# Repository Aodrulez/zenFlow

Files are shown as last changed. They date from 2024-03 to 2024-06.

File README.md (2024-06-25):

# ZenFlow
## My endgame 18 key custom keyboard 

Kailh Choc V1 variant:
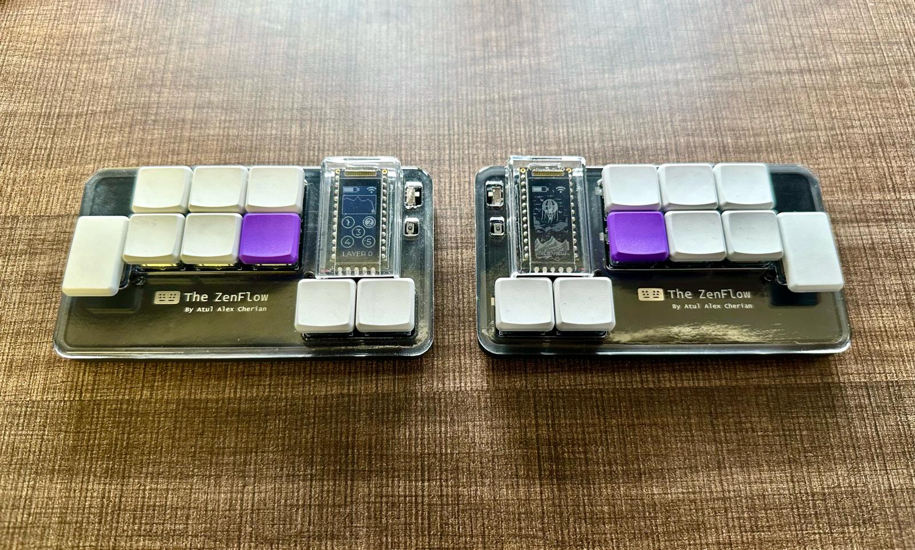
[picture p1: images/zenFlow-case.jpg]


MX 3d printed + hand wired variant:
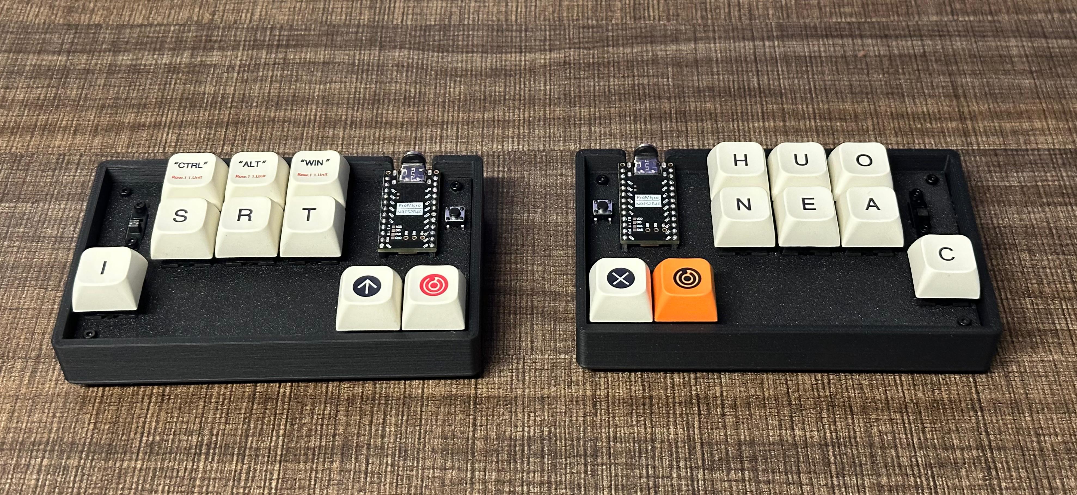
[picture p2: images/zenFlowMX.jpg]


ZenFlow is a fully custom split wireless keyboard made using Ergogen + KiCad. It's powered by [ZMK](https://zmk.dev/). Check [keymap](./keymap) for more details. 
## Features

- 18 keys
- Split, ortholinear
- Fully wireless, compatible with ZMK
- Supports both hot-swap as well as direct soldering of Kailh Choc v1 switches
- Supports nice!view displays
- Reversible PCB
- Mounting holes for a case

Note (Kailh Choc V1 variant): `Solder all the reversible pads & components (except battery, power switch & reset button) on the bottom side of each half as instructed on the PCB` 

## Requirements (Kailh Choc V1 variant)
| Part | Specification |
| --- | --- |
| MCU | 2x nice!nano or SuperMini |
| Battery | 2x Lipo battery (301230)|
| Power switch | 2x MSK-12C02 or compatible |
| Reset button | 2x B3U-1000P(M) |
| Switches | 18x Kailh Choc v1 |
| Keycaps | 16x Kailh Choc v1 1u & 2x Kailh Choc v1 2u |
| Hotswap sockets (Optional) | 18x Kailh Choc v1 |
| Display (Optional) | 2x nice!view |

## Credits
- Ben Vallack for the videos & his Piano keyboard for inspiration
- [Ergogen](https://docs.ergogen.xyz/) which was used for most of the designing & FlatFootFox for the tutorial series 
- [ZMK](https://zmk.dev/) community in general

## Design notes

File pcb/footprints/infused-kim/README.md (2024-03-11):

# @infused-kim's ergogen PCB footprints

> **Warning**
>
> These footprints have not been tested and are still under active development. Use them at your own risk.

1. [Installation](#installation)
    1. [How to add the footprints as a git submodule](#how-to-add-the-footprints-as-a-git-submodule)
    2. [How to use them in your ergogen config](#how-to-use-them-in-your-ergogen-config)
    3. [How to update the submodule](#how-to-update-the-submodule)
    4. [How to clone your ergogen repo](#how-to-clone-your-ergogen-repo)
2. [How to design or modify ergogen footprints](#how-to-design-or-modify-ergogen-footprints)
3. [License](#license)

## Installation

### How to add the footprints as a git submodule

Add the footprint library as a git submodule to your project...

```bash
git submodule add git@github.com:infused-kim/kb_ergogen_fp.git ergogen/footprints/infused-kim/
```

Make sure to adjust the path to a subfolder in your ergogen folder (`ergogen/footprints/infused-kim/` in the example above.)

### How to use them in your ergogen config

You can then use the footprints in your ergogen config.yaml:

```yaml
[...]
pcbs:
    your_keyboard:
        footprints:
            # Controller
            promicro:
                what: infused-kim/nice_nano_pretty
                params:
                    traces: true
                    show_via_labels: false
[...]
```

### How to update the submodule

To update to a newer version...

```bash
# Pull updates inside the submodule repo
cd ergogen/footprints/infused-kim/
git checkout main
git pull

# Update the submodule in the parent repo
cd ..
git add .
git commit -m "Updated infused-kim footprint submodule"
```

### How to clone your ergogen repo

Users who clone your ergogen repo, must also update the submodule. So you should instruct them to either clone with the `--recursive` mode...

```bash
git clone --recursive git@github.com:your-user/your-keyboard.git
```

Or do init and update the submodules in a repo that was already cloned repo without the `--recursive` argument...

```bash
git clone git@github.com:your-user/your-keyboard.git
cd your-keyboard
git submodule init && git submodule update
```

Git will load exactly the same version of the footprints that you used. So you don't need to worry about accidental updates to incompatible future versions.

## How to design or modify ergogen footprints

I wrote a [guide on how to convert KiCad footprints to ergogen that you can find here](https://www.notion.so/nilnil/Convert-Kicad-Footprint-to-Ergogen-8340ce87ad554c69af4e3f92bc9a0898?pvs=4).

If you want to modify any of the footprints here, you can find many of the original KiCad v5 footprint files I used or created in the [./kicad_footprints/](./kicad_footprints/) directory.

## License

**TLDR:**

- Personal use with attribution
- Commercial use not allowed

This work is licensed under a
[Creative Commons Attribution-ShareAlike 4.0 International License][cc-by-sa].

[][cc-by-sa]

[cc-by-sa]: http://creativecommons.org/licenses/by-sa/4.0/
[cc-by-sa-image]: https://licensebuttons.net/l/by-sa/4.0/88x31.png
[cc-by-sa-shield]: https://img.shields.io/badge/License-CC%20BY--SA%204.0-lightgrey.svg

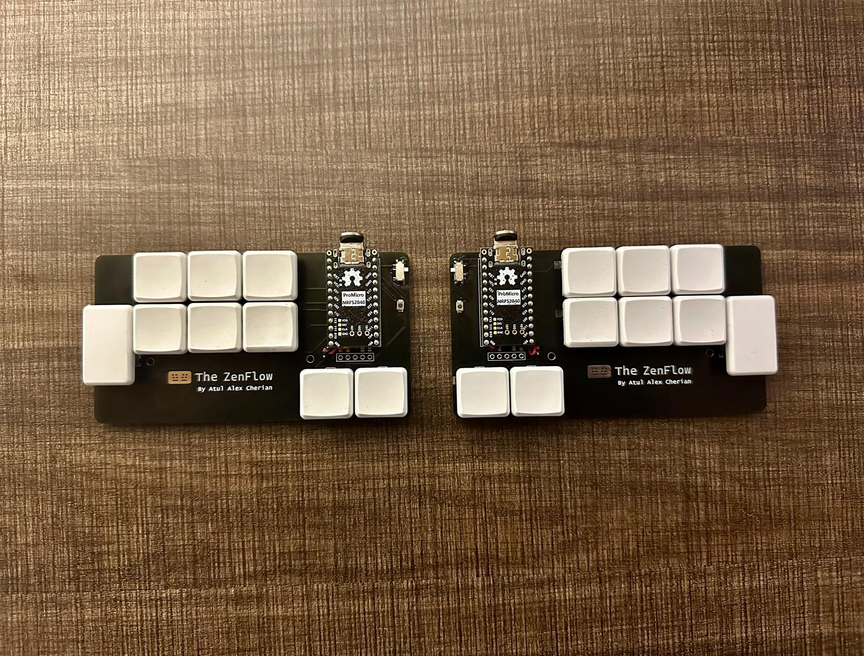
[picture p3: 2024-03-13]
images/zenFlow.jpg

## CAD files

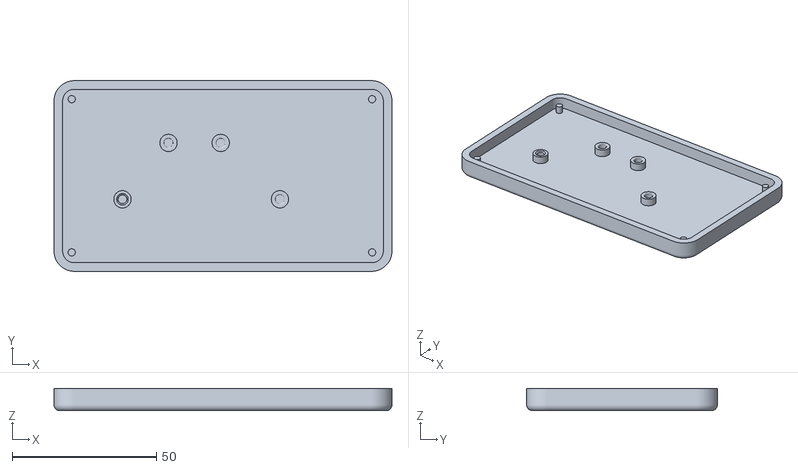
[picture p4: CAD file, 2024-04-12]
case/LowProfile/zenFlow-base-left.stl
117.0 x 66.0 x 7.70

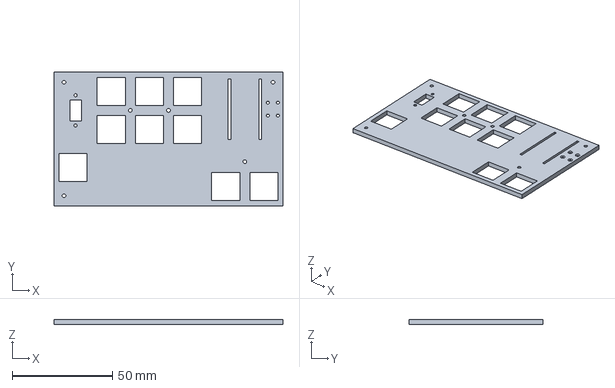
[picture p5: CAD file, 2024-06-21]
case/MX/zenFlowV2SwitchPlate.3mf
114.3 x 66.7 x 2.50 mm

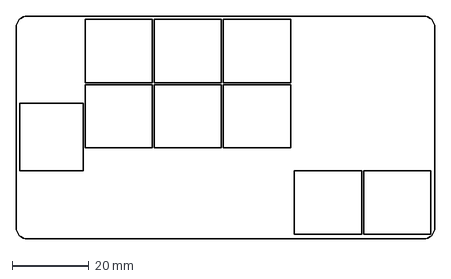
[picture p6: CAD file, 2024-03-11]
pcb/output/outlines/combo.dxf
109.0 x 58.0 mm

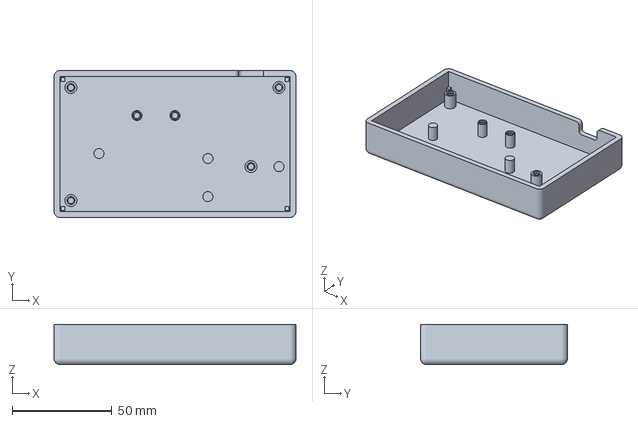
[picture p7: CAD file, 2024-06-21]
case/MX/zenFlowV2Case.3mf
121.3 x 73.7 x 20.1 mm

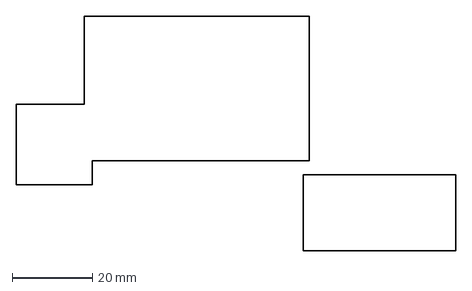
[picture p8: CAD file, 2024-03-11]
pcb/output/outlines/raw.dxf
109.5 x 58.4 mm

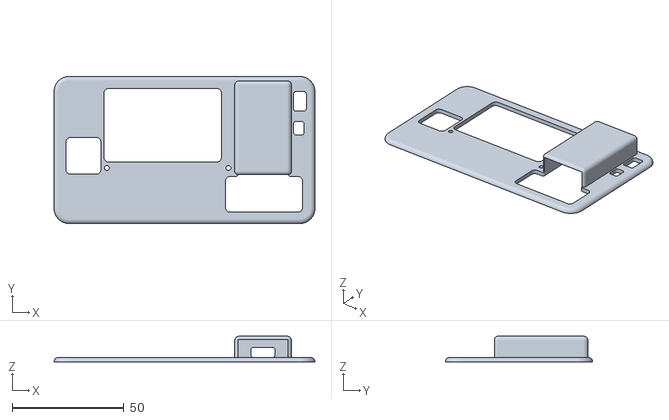
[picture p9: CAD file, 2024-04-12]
case/LowProfile/zenFlow-top-left.stl
117.0 x 66.0 x 11.5

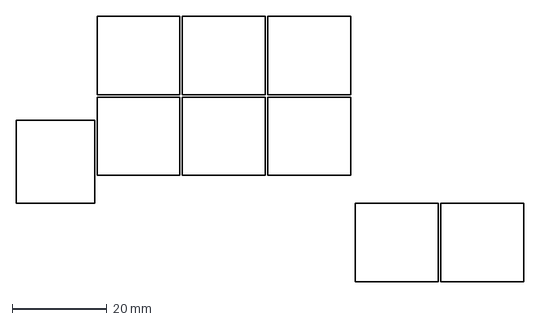
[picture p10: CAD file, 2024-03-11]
pcb/output/outlines/keys.dxf
107.0 x 55.9 mm

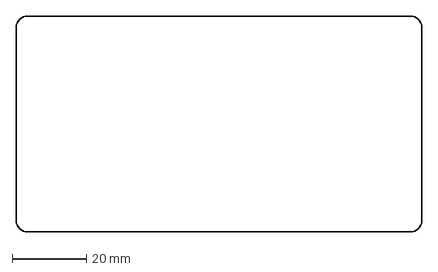
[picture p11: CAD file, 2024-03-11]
pcb/output/outlines/board.dxf
109.0 x 58.0 mm

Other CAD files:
case/LowProfile/zenFlow-base-right.stl
case/LowProfile/zenFlow-top-right.stl

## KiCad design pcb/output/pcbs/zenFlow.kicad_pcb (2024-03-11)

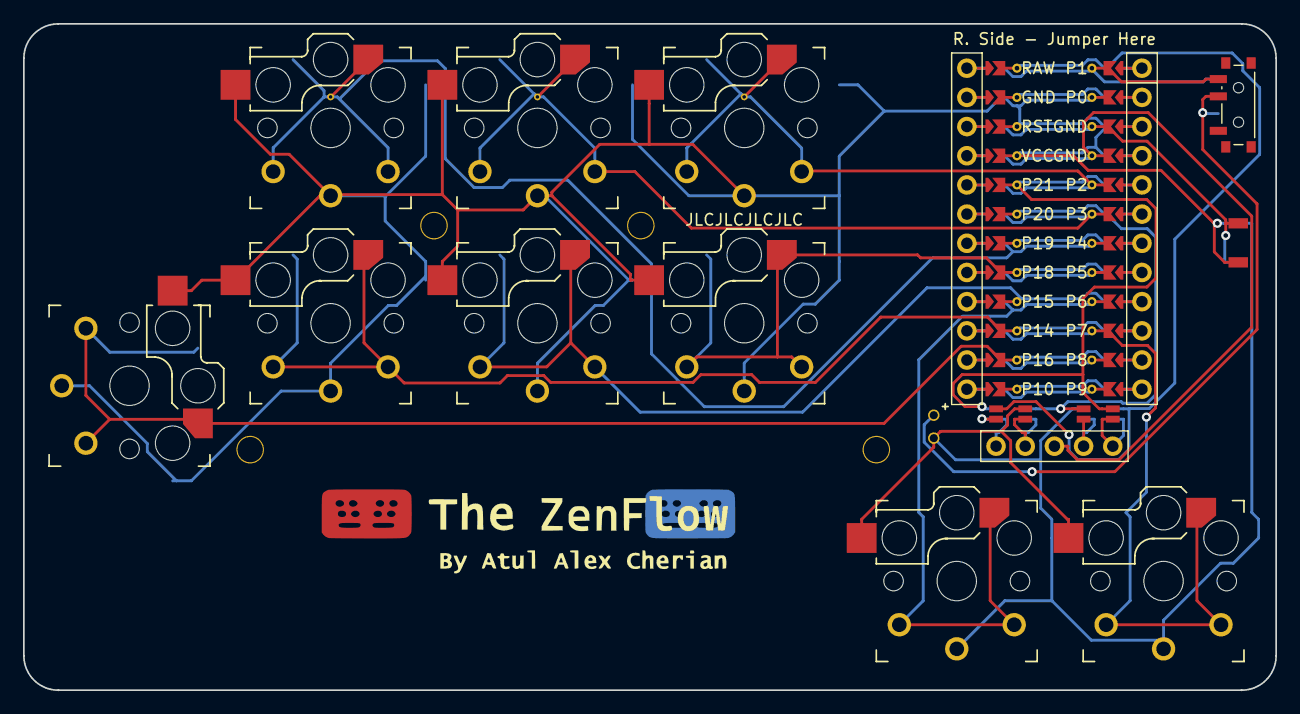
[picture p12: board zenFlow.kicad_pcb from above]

Board: 2 copper layers, 109.0 x 58.0 mm, 21 parts (0 on the bottom side), 21 nets.

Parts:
BAT: bat
DISP1: nice!view
H1, H2, H3, H4: mounting_hole
MCU1: nice_nano
S1, S2, S3, S4, S5, S6, S7, S8, S9: PG1350
S10: SW_SPST_B3U-1000P
SW1: power_switch
Via1, Via2, Via3: VIA-0.6mm

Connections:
BAT_P: BAT.2, SW1.2, SW1.5
DISP1_1: DISP1.1, DISP1.10, DISP1.23
DISP1_2: DISP1.2, DISP1.11, DISP1.22
DISP1_4: DISP1.4, DISP1.12, DISP1.21
DISP1_5: DISP1.5, DISP1.13, DISP1.20
GND: BAT.1, DISP1.15, DISP1.25, MCU1.2, MCU1.121, MCU1.122, S1.2, S2.2, S3.2, S4.2, S5.2, S6.2, S7.2, S8.2, S9.2, S10.2
P1: DISP1.14, DISP1.24, MCU1.124
P2: DISP1.17, DISP1.27, MCU1.120
P3: DISP1.16, DISP1.26, MCU1.119
P5: MCU1.117, S6.1
P6: MCU1.116, S4.1
P7: MCU1.115, S2.1
P8: MCU1.114, S1.1
P14: MCU1.10, S9.1
P15: MCU1.9, S8.1
P19: MCU1.7, S3.1, Via1.1
P20: MCU1.6, S5.1, Via2.1
P21: MCU1.5, S7.1, Via3.1
RAW: MCU1.1, SW1.3, SW1.6
RST: MCU1.3, S10.1
VCC: DISP1.3, MCU1.4
